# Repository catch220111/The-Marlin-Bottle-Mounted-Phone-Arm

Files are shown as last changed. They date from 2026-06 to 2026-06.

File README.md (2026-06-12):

# The Marlin Arm

**A bottle-mounted folding MagSafe phone arm.**

A slim strap wraps around any standard water bottle. A nested, articulated arm unfolds to hold your phone at eye level — the filled bottle is the counterweight. No tripod, no desk, no extra gear: if you already carry a bottle, you already carry your filming rig.

Built for athletes and coaches who film their own training, creators who shoot in the gym / kitchen / outdoors, and anyone who wants a hands-free phone setup without extra equipment. Part of [The Marlin](https://themarlin.app) project by [Studio Prajna](https://studioprajna.com).

> ⚠️ **Status: early prototype (v0/v2 concept).** Nothing here has been print-validated yet. Dimensions, tolerances, and the hinge stack-up will change. We're looking for funding and early users to make this shareable and far more accurate — contact **piranha@studioprajna.com**.

Concept image of the Marlin Arm in use
*Concept image — how the deployed arm would hold a phone for filming.*

---

## Repository layout

```
├── 3mf/    Colored assemblies (Onshape export) — best for viewing
│   ├── MarlinArmDeployed.3mf      full assembly, unfolded filming position
│   └── MarlinArmFolded.3mf        full assembly, collapsed pocket state
├── stl/    Numbered configuration exports (STEP + STL pairs)
├── scad/   v0 concept model (OpenSCAD, parametric)
└── py/     v2 parametric source (CadQuery 2.x) — generates everything in stl/
```

### The numbered exports (`stl/`)

Each configuration ships as a **STEP** (editable, exact B-rep — use this in CAD) and an **STL** (mesh — use this for quick viewing or slicing).

| # | File | What it shows |
|---|---|---|
| 01 | `01_strap_flat` | Strap in manufacturing layout: 15 mm webbing, fold-back sewn loop with box-X stitch zone, hidden TPU liner, tri-glide slider |
| 02 | `02_strap_curled` | Strap wrapped around a Ø92 mm reference bottle |
| 03 | `03_arm_extended` | Arm chain fully extended with the MagSafe head open |
| 04 | `04_arm_folded_stick` | Arm nested into its folded "stick" — the head folds flat as the end cap |
| 05 | `05_full_assembly_deployed` | Everything on the bottle, deployed in the zig-zag filming pose |
| 06 | `06_full_assembly_folded` | Everything on the bottle, collapsed flat |
| 07 | `07_hinge_stackup_exploded` | One hinge joint exploded along its pin axis — shows the clevis walls, PTFE friction washers, and shoulder pin |

---

## How it works (mechanical logic)

The v2 source encodes the actual engineering intent, not just shapes:

**Strap routing (belt logic).** The fixed end of the webbing loops through the spine bracket's lower slot and is sewn back on itself — the spine is *captured* by the strap, not glued. The free end wraps the bottle, returns through the upper slot, and is held by a low-profile tri-glide slider. Tension range fits **Ø83–95 mm bottles**.

**Hidden grip liner.** A 24 mm × 1.5 mm TPU liner — wider than the visible 15 mm webbing — is bonded to the strap's inner face under the spine. It spreads bearing pressure onto the bottle and provides the anti-rotation friction couple.

**Force path.**
`phone → MagSafe head → arm 3 → arm 2 → arm 1 → base pin → spine clevis ears → spine plate → TPU liner (friction × strap tension) → bottle wall` — and the bottle's mass is the counterweight against tipping.

**Nested hinge stack-up.** Each smaller arm's end sits inside the larger arm's channel, so the channel walls *are* the clevis — no extra knuckle hardware. Every joint, outside-in: shoulder-pin head | outer wall | friction washer | inner part | friction washer | outer wall | lock nut. 0.7 mm PTFE washers set the holding torque.

**Fold kinematics.** All three segments are modeled in the folded nest; the extended and deployed poses are generated by rotating the chain about the real pin axes, child-first. Pin axes are staggered 12 mm in X and offset in Z so adjacent pins never collide.

---

## Regenerating the models (`py/marlin_v2.py`)

The v2 source is a [CadQuery 2.x](https://github.com/CadQuery/cadquery) script. All seven STEP/STL configurations are generated from it.

```bash
pip install cadquery
# edit the OUT path near the top of the script first:
#   OUT = "/home/claude/marlin/out_v2"   ← change to your output dir
python py/marlin_v2.py
```

Key parameters live at the top of the script — strap length/width, segment span (`SEG_L`), channel widths for the three nested arms, pin radius, MagSafe plate/ring dimensions. Change a number, rerun, and all seven configurations re-export consistently.

### The v0 concept (`scad/themarlinwaterbottlev0.scad`)

The original sketch in OpenSCAD: a simpler 3-segment arm (3 × 100 mm) with ball-joint MagSafe head and an accessory loop on the strap. Kept for reference — open it in [OpenSCAD](https://openscad.org), tweak the hinge angles in the customizer to fold/unfold, and set `show_bottle = false` before exporting for print. **The v2 CadQuery model supersedes it.**

---

## Bill of materials (non-printed parts, v2)

| Part | Spec | Qty |
|---|---|-----|
| Webbing strap | 15 mm × 290 mm × 2 mm | 1 |
| TPU grip liner | 24 mm × 280 mm × 1.5 mm | 1 |
| Tri-glide slider | 15 mm, low profile | 1 |
| Shoulder pins | Ø7 mm (bore Ø3.2–4.2 spec) | 4 |
| PTFE friction washers | Ø12 mm OD × 0.7 mm | 8 |
| Rivets | Ø3 mm (strap + liner + spine tab) | 2 |
| MagSafe ring/magnet array | Ø56 mm OD | 1 |

Spine bracket: 6061 aluminium or glass-filled nylon. Arms: PLA is fine for prototyping; the channels print open-side-up without support at 0.2 mm layers.

---

## Contributing & contact

This is an open hardware project in its earliest stage. Print attempts, tolerance feedback, strap-material suggestions, and redesigns are all welcome — open an issue or write to **piranha@studioprajna.com**.

## License

[MIT](LICENSE) — print it, remix it, build on it. Attribution appreciated.

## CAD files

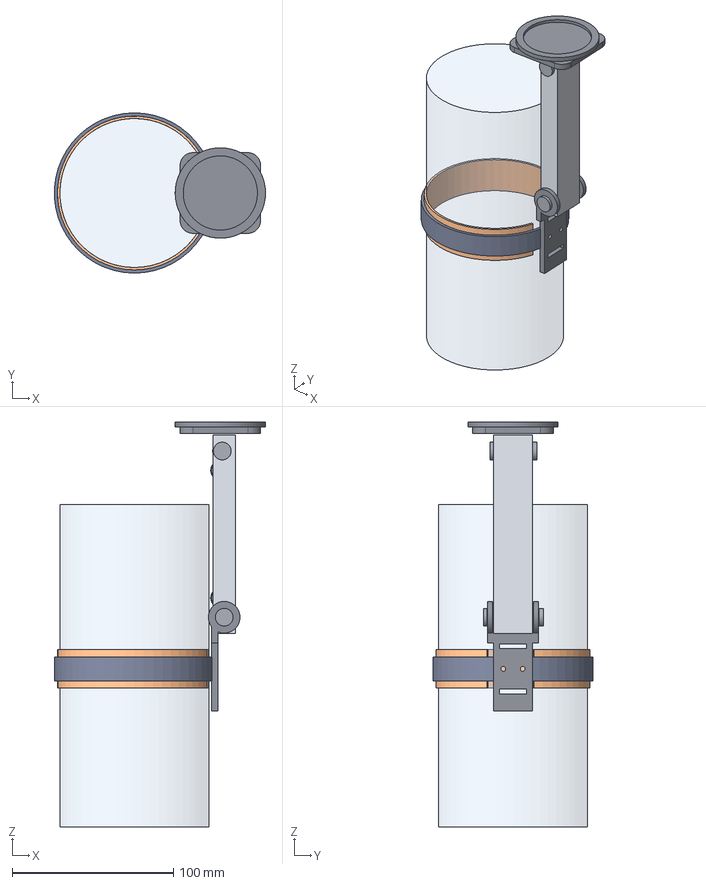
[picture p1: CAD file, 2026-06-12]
stl/06_full_assembly_folded.step
130.8 x 99.3 x 251.0 mm
bottle_ref
webbing
tpu_liner
head
pin3
arm3
wash3
pin2
arm2
wash2
pin1
arm1
wash1
pin0
wash0
spine

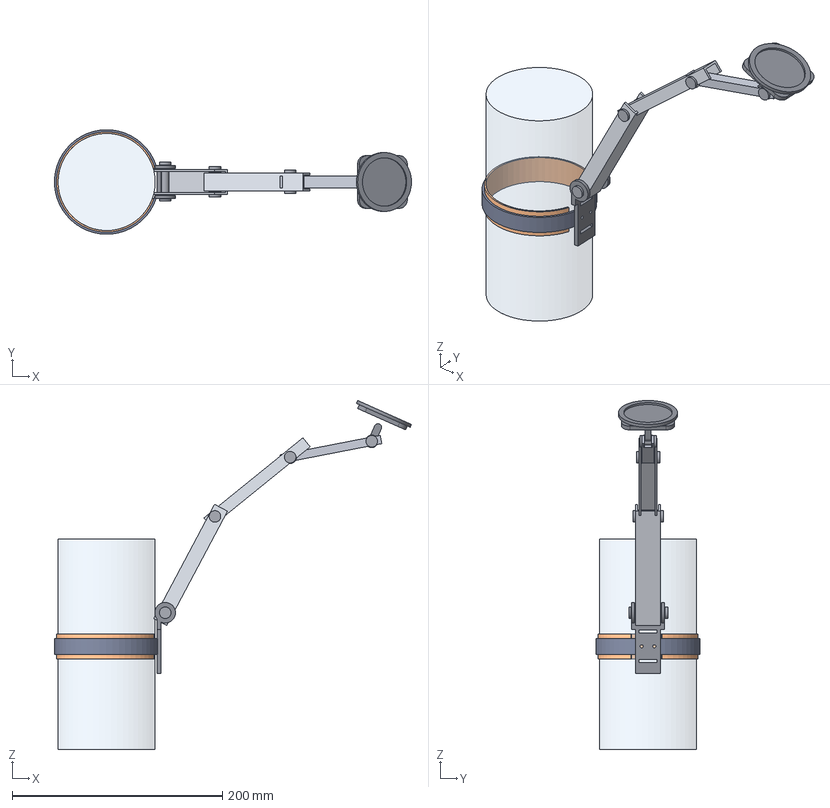
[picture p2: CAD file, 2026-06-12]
stl/05_full_assembly_deployed.step
339.3 x 99.3 x 331.7 mm
bottle_ref
webbing
tpu_liner
head
pin3
arm3
wash3
pin2
arm2
wash2
pin1
arm1
wash1
pin0
wash0
spine

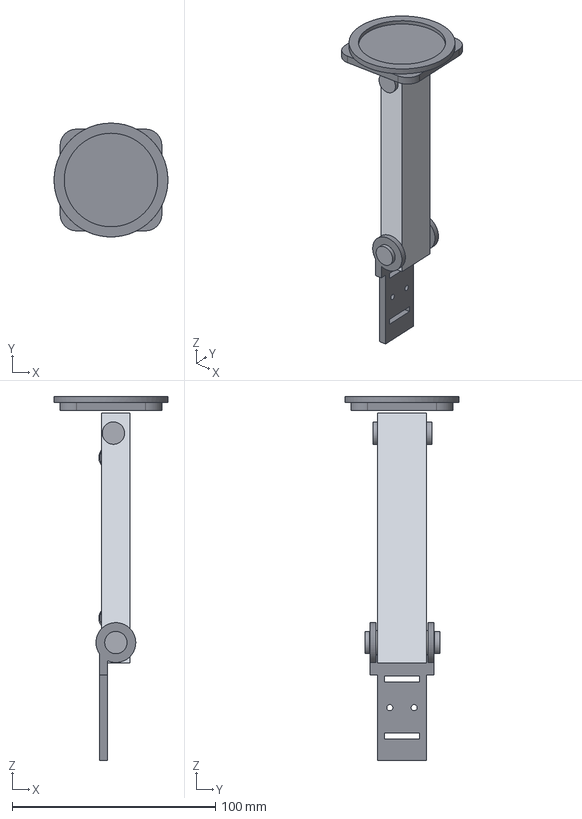
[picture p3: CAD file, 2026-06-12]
stl/04_arm_folded_stick.step
56.0 x 56.0 x 179.0 mm
head
pin3
arm3
wash3
pin2
arm2
wash2
pin1
arm1
wash1
pin0
wash0
spine

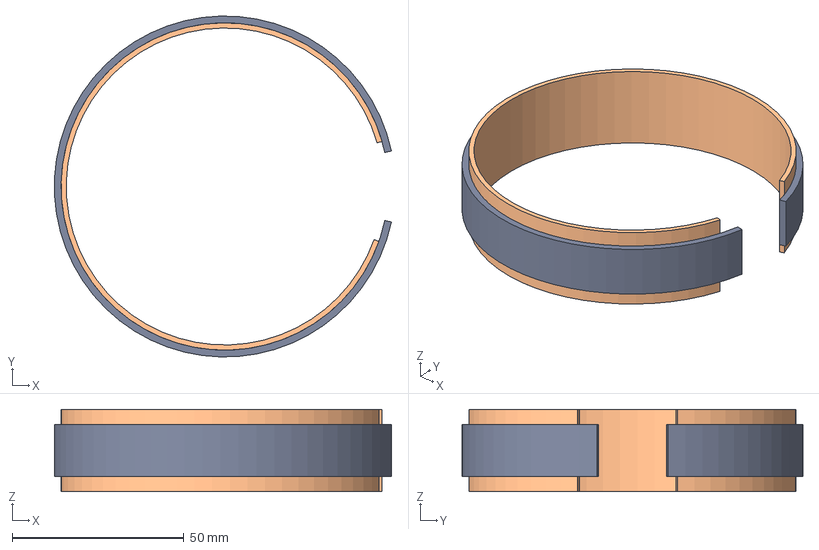
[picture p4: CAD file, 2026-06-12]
stl/02_strap_curled.step
98.2 x 99.3 x 24.0 mm
webbing
tpu_liner

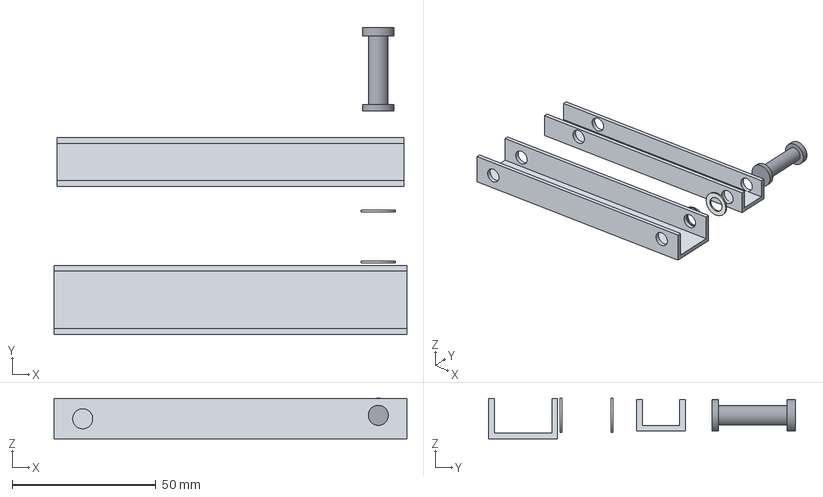
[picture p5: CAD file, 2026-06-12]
stl/07_hinge_stackup_exploded.step
123.0 x 106.8 x 14.2 mm
arm1_clevis_walls
friction_washers
arm2_tongue
shoulder_pin_and_nut

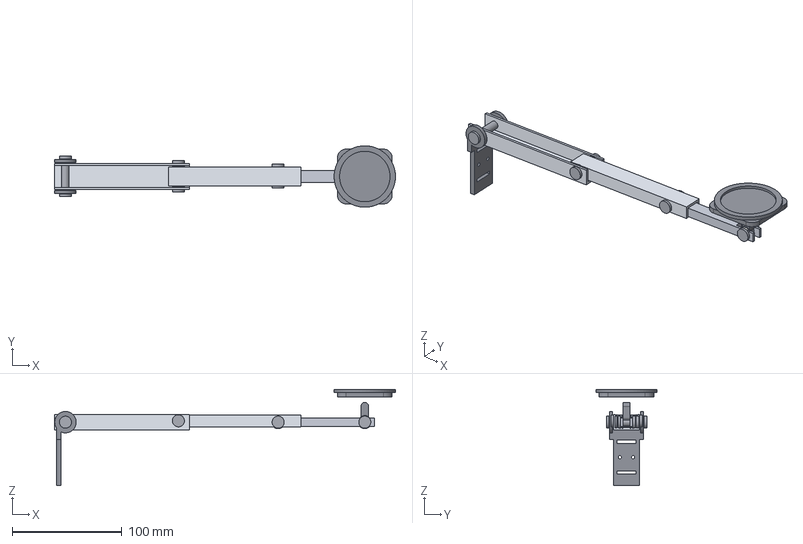
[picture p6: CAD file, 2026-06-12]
stl/03_arm_extended.step
311.0 x 56.0 x 88.0 mm
head
pin3
arm3
wash3
pin2
arm2
wash2
pin1
arm1
wash1
pin0
wash0
spine

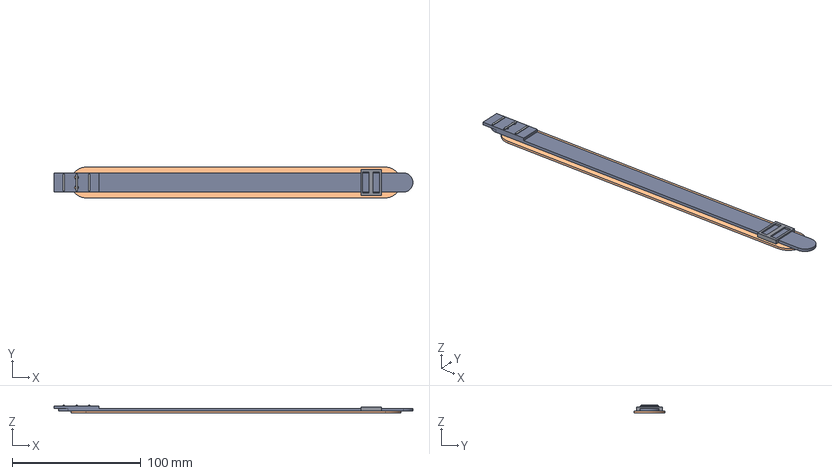
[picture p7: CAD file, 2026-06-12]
stl/01_strap_flat.step
278.5 x 24.0 x 6.00 mm
webbing
stitches
tpu_liner
slider

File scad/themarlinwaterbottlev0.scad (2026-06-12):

// MagSafe Water Bottle Mount - Conceptual Prototype
// Units: mm

/* [Parameters] */
bottle_radius = 45;       // Adjust for your specific bottle (45mm = 90mm diameter)
bottle_height = 200;      
strap_thickness = 4;
strap_height = 35;
arm_length = 100;         // 3 segments of 100mm = 30cm total extension
arm_width = 20;
arm_thickness = 6;
magsafe_radius = 28;      // Standard Apple MagSafe puck size
magsafe_thickness = 6;

/* [Hinge Angles] */
// Adjust these to fold or unfold the arm
angle_1 = 30;   // Base hinge
angle_2 = -150; // Middle hinge
angle_3 = 140;  // Top hinge
head_tilt = 20; // MagSafe head tilt

/* [Rendering] */
show_bottle = true;       // Set to false before exporting for 3D printing

// --- MODULES ---

module water_bottle() {
    if(show_bottle) {
        // Renders as a transparent "ghost" object for reference
        %cylinder(r=bottle_radius, h=bottle_height, $fn=100);
    }
}

module base_strap() {
    // The main silicone/fabric ring
    difference() {
        cylinder(r=bottle_radius + strap_thickness, h=strap_height, $fn=100);
        translate([0, 0, -1])
            cylinder(r=bottle_radius, h=strap_height + 2, $fn=100);
    }
    
    // Hinge Mount Anchor
    translate([bottle_radius + strap_thickness/2, -arm_width/2, 0])
        cube([10, arm_width, strap_height]);

    // Accessory Loop (for pens, keys, or MOLLE attachments)
    translate([-(bottle_radius + strap_thickness + 8), -15, 0])
        difference() {
            cube([8, 30, strap_height]);
            translate([2, 2, -1]) 
                cube([4, 26, strap_height + 2]);
        }
}

module arm_segment() {
    // Basic arm structure with rounded hinge ends
    union() {
        translate([-arm_thickness/2, -arm_width/2, 0])
            cube([arm_thickness, arm_width, arm_length]);
        
        // Bottom hinge joint
        rotate([90, 0, 0]) 
            cylinder(r=arm_thickness/2, h=arm_width, center=true, $fn=30);
            
        // Top hinge joint
        translate([0, 0, arm_length])
            rotate([90, 0, 0]) 
                cylinder(r=arm_thickness/2, h=arm_width, center=true, $fn=30);
    }
}

module magsafe_head() {
    // The puck holder
    cylinder(r=magsafe_radius, h=magsafe_thickness, $fn=60);
    
    // Simple ball joint connector
    translate([0, 0, -5]) 
        sphere(r=8, $fn=40);
        
    // Connector neck
    translate([0, 0, -5])
        cylinder(r=4, h=5, $fn=30);
}

// --- ASSEMBLY (Kinematic Chain) ---

water_bottle();

// Center the strap on the bottle
translate([0, 0, bottle_height/3]) {
    base_strap();

    // Hinge 1 (Base)
    translate([bottle_radius + strap_thickness + 5, 0, strap_height/2]) {
        rotate([0, angle_1, 0]) {
            arm_segment();

            // Hinge 2 (Middle)
            translate([0, 0, arm_length]) {
                rotate([0, angle_2, 0]) {
                    arm_segment();

                    // Hinge 3 (Top)
                    translate([0, 0, arm_length]) {
                        rotate([0, angle_3, 0]) {
                            arm_segment();

                            // MagSafe Head Mount
                            translate([0, 0, arm_length]) {
                                rotate([0, head_tilt, 0]) {
                                    // Orient the puck to face the user
                                    rotate([0, 90, 0]) 
                                        magsafe_head();
                                }
                            }
                        }
                    }
                }
            }
        }
    }
}

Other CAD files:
3mf/MarlinArmFolded.3mf
3mf/MarlinArmDeployed.3mf
stl/01_strap_flat.stl
stl/02_strap_curled.stl
stl/03_arm_extended.stl
stl/04_arm_folded_stick.stl
stl/05_full_assembly_deployed.stl
stl/06_full_assembly_folded.stl
stl/07_hinge_stackup_exploded.stl

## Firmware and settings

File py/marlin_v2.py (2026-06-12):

"""
THE MARLIN v2 — Parametric CAD source (CadQuery 2.x)  |  units: mm
====================================================================
Bottle-mounted folding MagSafe phone arm. Strap-based mount (no clamp
pads), hidden TPU anti-rotation liner, rigid load-bearing spine,
nested tapered folding arms, MagSafe head folds flat as the end cap.

MECHANICAL LOGIC ENCODED IN THIS MODEL
--------------------------------------
Strap routing (belt logic):
  * Fixed end of the 15 mm webbing loops through the spine's LOWER
    slot and is sewn back on itself (box-X stitch zone, modeled as
    stitch ridges) -> the spine is CAPTURED by the strap, not glued.
  * Free end wraps the bottle, enters the spine's UPPER slot from
    outside, doubles back, and is held by a low-profile slider
    (tri-glide). Tension range accommodates Ø83-95 mm bottles.
  * Two Ø3 rivets through webbing + TPU liner + spine lower tab lock
    the layers against creep/slip (backup to stitching).

Hidden grip liner:
  * 24 mm wide x 1.5 mm TPU liner bonded to the strap's inner face,
    WIDER than the 15 mm visible webbing, centered under the spine
    zone -> spreads the spine's bearing pressure onto the bottle and
    provides the anti-rotation friction couple.

Force path:
  phone -> MagSafe head -> arm3 -> pin3 -> arm2 -> pin1 -> arm1
  -> base pin (shear) -> spine clevis ears -> spine plate (bending
  over its 58 mm height) -> TPU liner (friction x strap tension)
  -> bottle wall; bottle mass = counterweight against tipping.

Hinge stack-up (every joint, outside -> in):
  shoulder-bolt head | outer wall | [friction washer | inner part |
  friction washer] | outer wall | lock nut.
  The nested-channel walls ARE the clevis: each smaller arm's end
  sits inside the larger arm's channel, so the pivot needs no extra
  knuckle hardware. PTFE friction washers (0.7 mm) set holding torque.

Fold kinematics (proves no collision):
  All three segments are modeled in the FOLDED nest. Every other
  configuration (extended / deployed) is generated by rotating the
  chain about the real pin axes, child-first. Pin axes are staggered
  12 mm in X and offset in Z so adjacent pins never intersect.
"""

import math, os
import cadquery as cq
from cadquery import exporters

# ============================================================
# PARAMETERS
# ============================================================
# ---- Strap ----
STRAP_W   = 15.0      # visible webbing width
STRAP_L   = 290.0     # flat webbing length
STRAP_T   = 2.0       # webbing thickness
PATCH_W   = 24.0      # hidden TPU liner width (wider than webbing)
PATCH_L   = 280.0     # liner length
PATCH_T   = 1.5       # liner thickness
SEW_LOOP  = 35.0      # fold-back sewn length at fixed end
WRAP_GAP  = 24.0      # degrees of opening in curled state
BOTTLE_R  = STRAP_L / (2 * math.pi)   # ~46.2 -> Ø92 bottle at nominal

# ---- Spine bracket (6061 alu or glass-filled nylon) ----
SPINE_T   = 4.0
SPINE_H   = 58.0
SPINE_W   = 24.0      # matches liner width
SLOT_W    = 17.0      # strap slots (webbing 15 + 2)
SLOT_H    = 3.0
EAR_R     = 9.8       # base hinge knuckle radius (spec 9.5-9.8)
EAR_T     = 3.0

# ---- Arms (nested channels; channel opens +Z in folded nest) ----
SEG_L     = 103.0     # pin-to-pin major span
WALL      = 2.0
CLEAR     = 0.7
A1_W, A1_D = 24.0, 14.0      # outer channel
A2_W, A2_D = 17.0, 11.0      # middle channel
A3_W, A3_D = 11.0,  8.0      # inner solid bar
END        = 10.0            # end margin beyond pin bores
STAG       = 12.0            # X-stagger between near-end pins

# ---- Hinge hardware ----
PIN_R     = 3.5       # spec 3.2-4.2
WASH_OD   = 12.0
WASH_T    = 0.7       # PTFE friction washer

# ---- MagSafe head ----
HEAD_S    = 50.0      # plate square
HEAD_T    = 4.0
RING_OD   = 56.0
RING_T    = 3.0
TAB_W     = 6.0

OUT = "/home/claude/marlin/out_v2"
os.makedirs(OUT, exist_ok=True)

# colors
C_WEB   = cq.Color(0.13, 0.18, 0.32)
C_TPU   = cq.Color(0.95, 0.55, 0.25)   # liner highlighted orange
C_AL    = cq.Color(0.66, 0.69, 0.74)
C_AL2   = cq.Color(0.52, 0.55, 0.62)
C_DARK  = cq.Color(0.22, 0.24, 0.29)
C_PIN   = cq.Color(0.35, 0.37, 0.42)
C_WASH  = cq.Color(0.90, 0.90, 0.85)
C_GHOST = cq.Color(0.55, 0.70, 0.85, 0.25)

# ============================================================
# FRAME: base hinge axis = Y-axis through origin.
# Arm chain modeled FOLDED, lying along +X, nest floor at z=-7.
# Pin axes (folded frame, XZ coords), all axes parallel to Y:
A0 = (0.0, 0.0)                    # spine <-> arm1
A1 = (SEG_L, 1.2)                  # arm1 <-> arm2   (z: nest stack-up)
A2 = (STAG, 2.4)                   # arm2 <-> arm3   (staggered 12 mm)
A3 = (SEG_L - STAG, 2.4)           # arm3 <-> head
# ============================================================

def ybore(wp, x, z, r=PIN_R, span=40):
    """Cut a Y-axis bore through everything at (x, z)."""
    drill = (cq.Workplane("XZ", origin=(x, span / 2, z))
             .circle(r).extrude(span))
    return wp.cut(drill)

def ycyl(x, z, y0, y1, r):
    """Y-axis cylinder from y0 to y1 at (x, z)."""
    return (cq.Workplane("XZ", origin=(x, -y0, z))   # XZ normal = -Y
            .circle(r).extrude(y1 - y0))

# ------------------------------------------------------------
# ARMS
# ------------------------------------------------------------
def channel(x0, x1, w_out, half_in, z_bot, z_top, floor):
    """Open-ended U-channel along X, opening +Z."""
    L, xm = x1 - x0, (x0 + x1) / 2
    body = (cq.Workplane("XY", origin=(xm, 0, z_bot))
            .rect(L, w_out).extrude(z_top - z_bot))
    cut = (cq.Workplane("XY", origin=(xm, 0, z_bot + floor))
           .rect(L + 2, half_in * 2).extrude(z_top - z_bot))
    return body.cut(cut)

# arm1: 24x14 channel, z -7..7, inner half-width 10, floor 2
arm1 = channel(-END, SEG_L + END, A1_W, 10.0, -7.0, 7.0, WALL)
arm1 = ybore(arm1, *A0); arm1 = ybore(arm1, *A1)

# arm2: 17x11 channel, z -4.3..6.7 (nests in arm1 with 0.7 clearance)
arm2 = channel(-END + 1, SEG_L + END - 1, A2_W, 6.5, -4.3, 6.7, WALL)
arm2 = ybore(arm2, *A1); arm2 = ybore(arm2, *A2)

# arm3: 11x8 solid bar, z -1.6..6.4, clevis slot at head end
arm3 = (cq.Workplane("XY", origin=((A2[0] - 9 + A3[0] + 9) / 2, 0, -1.6))
        .rect(A3[0] - A2[0] + 18, A3_W).extrude(8.0))
slot = (cq.Workplane("XY", origin=(A3[0] + 4, 0, -2.6))
        .rect(28, TAB_W + CLEAR).extrude(11))
arm3 = arm3.cut(slot)
arm3 = ybore(arm3, *A2); arm3 = ybore(arm3, *A3)
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
